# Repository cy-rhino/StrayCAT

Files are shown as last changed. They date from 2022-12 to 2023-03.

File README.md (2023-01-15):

# StrayCAT
EtherCAT slave board using LAN9252

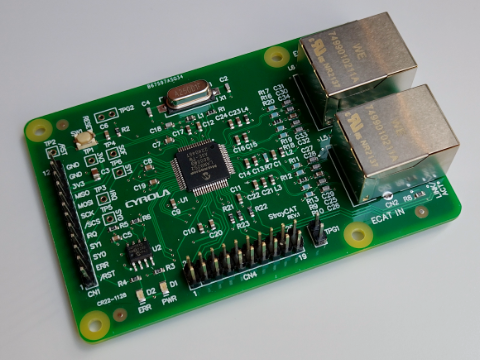
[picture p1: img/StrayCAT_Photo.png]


The design CAD is CircuitStudio. Board dimensions and hole locations are Raspberry Pi compliant, but other component placement is original and not mechanically compatible with any product. The SPI communication port conforms to the EasyCAT PRO pinout.

This stray board has not been tested by EtherCAT conformance testing and does not have the EtherCAT logo printed on it.

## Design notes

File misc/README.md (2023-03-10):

### Misc. Codes
This directory stores miscellaneous source code.

- StrayCAT_Master  
C# implementation software master for Windows  

- StrayCAT_Slave  
Test sketch using Arduino based slave device

##### Special Thanks
This repository builds on ideas and techniques devised by pioneers. I would like to pay special tribute to the following people and organizations.

- Bizan Nishimura, [SOEM.NET](https://github.com/lipoyang/SOEM.NET) conceptor
- Hernando Barragán, Arduino originator
- AB&T, EasyCAT and the Library developer
- RT-Labs, Open EtherCAT Society

##### Trademark
EtherCAT is registered trademark and patented technology, licensed by Beckhoff Automation GmbH, Germany.

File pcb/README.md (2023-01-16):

### PCB Layout

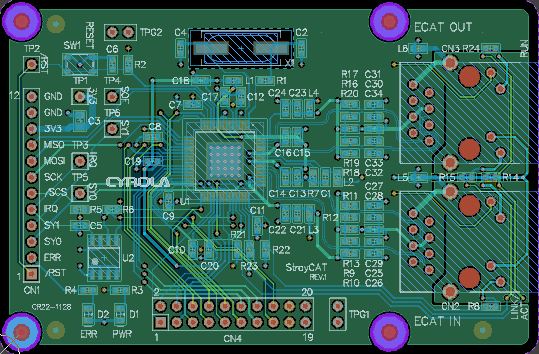
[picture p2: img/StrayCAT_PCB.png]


### PCB Order Information

| Item | Value |
|:---|:---|
| Size | 85mm * 56mm |
| Layers | 4Layers |
| Thickness | 1.6mm |
| Min Track/Spacing | 5/5mil |
| Min Hole Size | 0.3mm |
| Finished Copper | 1oz. Cu |

The order of the layers are as follows.

| Layer | Filename | Usage  |
|:---|:---|:---|
| L1 | StrayCAT.GTL | Top |
| L2 | StrayCAT.G1  | GND |
| L3 | StrayCAT.G2  | 3.3V |
| L4 | StrayCAT.GBL | Bottom |

- GTP layer allows simultaneous production of paste mask.
- GKO layer assigns the board outline.
- TXT file assigns the NC drill data.

### Layer Stack-up 

This Gerber data is impedance-matched based on the assumption that the order will be placed with a factory that manufactures the following board specifications.

| Item | Value |
|:---|:---|
|Trace Thickness | 0.035mm(1.378mil)  |
|Dielectric Thickness | 0.175mm(6.89mil) |
|Dielectric Constant  | 4.29 |

The trace width of the MDI transmission line is 6.929mil and the trace spacing is adjusted to 5.41mil so that the differential impedance is 100 ohms.

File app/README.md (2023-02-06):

# StrayCAT ESI Tool
 ESI .xml file generator

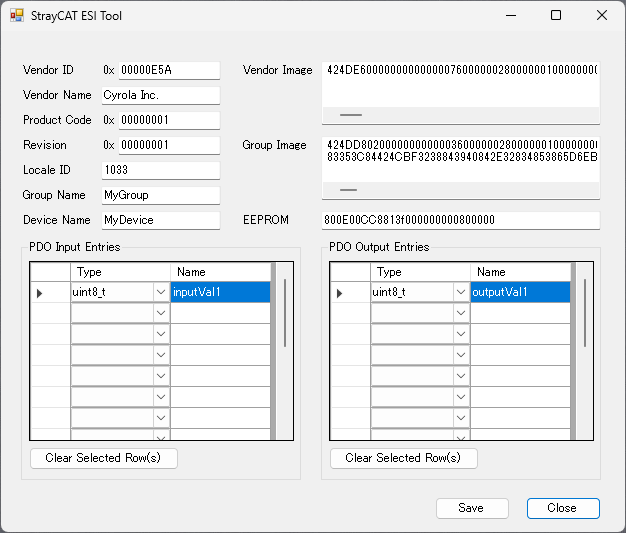
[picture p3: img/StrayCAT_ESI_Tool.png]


This tool is developed in VB.NET. It has only one form and the source code is written in a concise manner. The parameters that cannot be set in the form are hard-coded, so they can be easily modified using Visual Studio.

Originally, a function to write out binary file is also needed, but I do not plan to implement it because I do not have the necessary knowledge. A write tool is required to write the ESI to the EEPROM on the StrayCAT board. This tool is included in the archive of the ET9300 EtherCAT SSC Tool provided by Beckhoff.

To simplify checking the operation, a header file is output for use with the EasyCAT library.

This tool has not yet been fully tested. Users must check the generated xml and correct any problems they find.

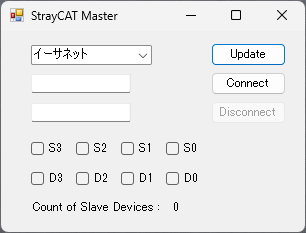
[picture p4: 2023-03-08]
img/StrayCAT_Master.png

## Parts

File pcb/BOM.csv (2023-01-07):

Designator | Qty. | Manufacturer Part Number | Description | Manufacturer
C1, C5, C6, C7, C8, C9, C10, C11, C12, C14, C16, C19, C20, C22, C24 | 15 | CGA3E2X7R1H104K080AA | 1608 0.1uF 50V X7R 10% | TDK
C2, C4 | 2 | CGA3E2C0G1H180J080AA | 1608 18pF 50V C0G 5% | TDK
C3 | 1 | CGA4J1X5R1C106K125AC | 2012 10uF 16V X5R 10% | TDK
C13, C15, C17, C21, C23 | 5 | CGA3E1X7R1E105K080AC | 1608 1uF 25V X7R 10% | TDK
C18 | 1 | CGA3E2C0G1H471J080AA | 1608 470pF 50V C0G 5% | TDK
C25, C26, C27, C28, C30, C31, C32, C33 | 8 | CGA3E2C0G1H100D080AA | 1608 10pF 50V C0G 5% | TDK
C29, C34 | 2 | CGA3E2X7R1H223K080AA | 1608 0.022uF 50V X7R 10% | TDK
CN2, CN3 | 2 | 7499010211A | WE-RJ45LAN | Würth Elektronik
D1 | 1 | APT2012QGW | 2012 Chip LED Green | Kingbright
D2 | 1 | APT2012NW | 2012 Chip LED Orange | Kingbright
L1, L2, L3, L4 | 4 | BLM18EG221SN1D | Chip Ferrite Bead | Murata
L5, L6 | 2 | BLM18PG330SN1D | Chip Ferrite Bead | Murata
R1, R13, R20 | 3 | RK73Z1JTTD | 1608 0-Ohm 1A | KOA
R2, R21, R22, R23 | 4 | RK73B1JTTD103J | 1608 10kOhm 5% 1/10W | KOA
R3, R4, R8, R14, R15, R24 | 6 | RK73B1JTTD102J | 1608 1kOhm 5% 1/8W | KOA
R5, R6 | 2 | RK73B1JTTD472J | 1608 4.7kOhm 5% 1/10W | KOA
R7 | 1 | RK73H1JTTD1212F | 1608 12.1kOhm 1% 1/10W | KOA
R9, R10, R11, R12, R16, R17, R18, R19 | 8 | RK73H1JTTD49R9F | 1608 49.9Ohm 1% 1/8W | KOA
SW1 | 1 | SKRPABE010 | SPST Switch N/O 1.57N | ALPS
U1 | 1 | LAN9252I/PT | EtherCAT Slave Controller | Microchip
U2 | 1 | 24FC512-I/SN | 512kBit I2C Serial EEPROM | Microchip
X1 | 1 | ABLS-25.000MHZ-B2F-T | HC/49US 25MHz Crystal | Abracon

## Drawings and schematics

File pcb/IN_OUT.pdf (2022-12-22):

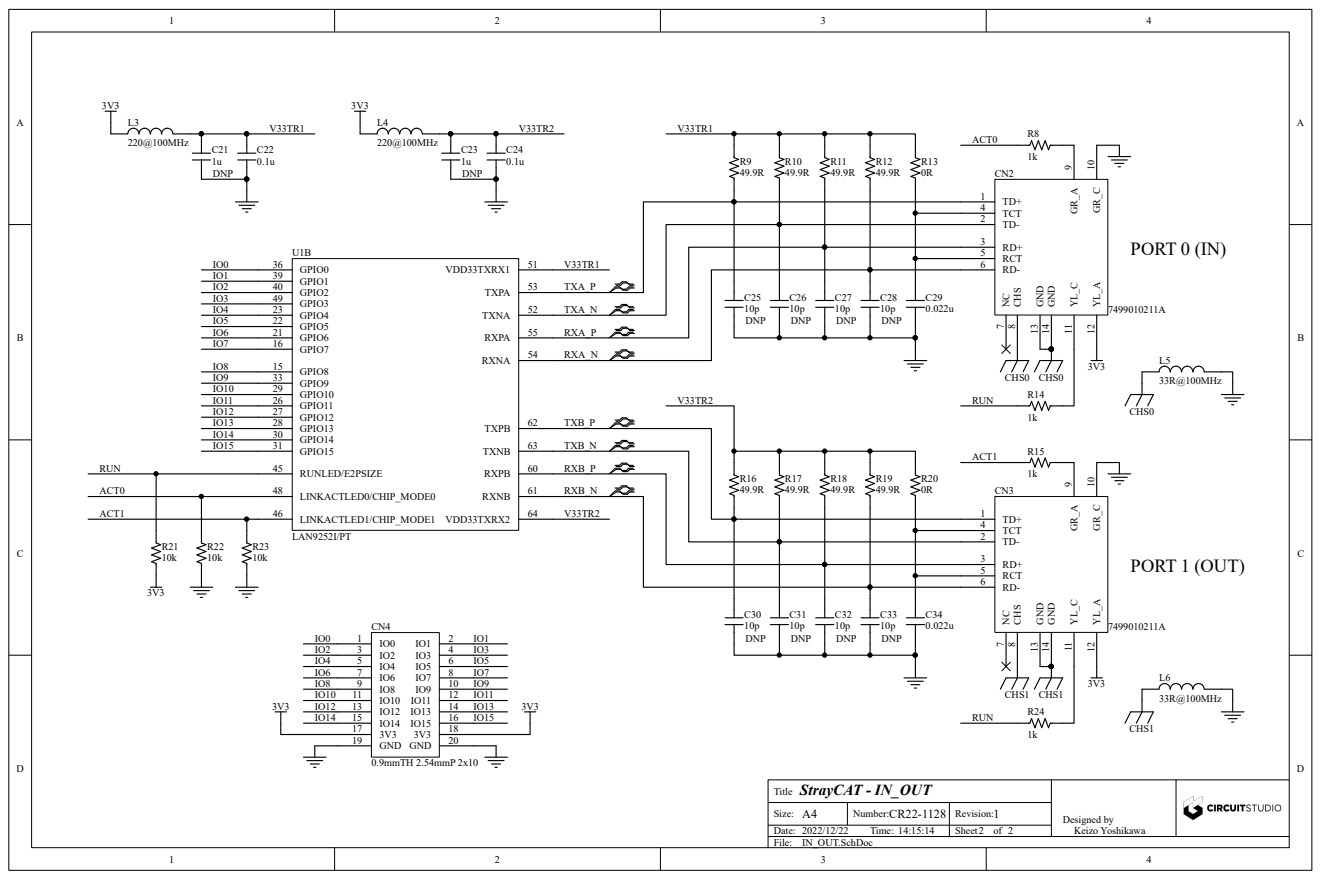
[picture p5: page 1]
Str; RUN; RXN; RUN ACT0 ACT1; RUN RUN; CHS 8; GND 13; GND 14

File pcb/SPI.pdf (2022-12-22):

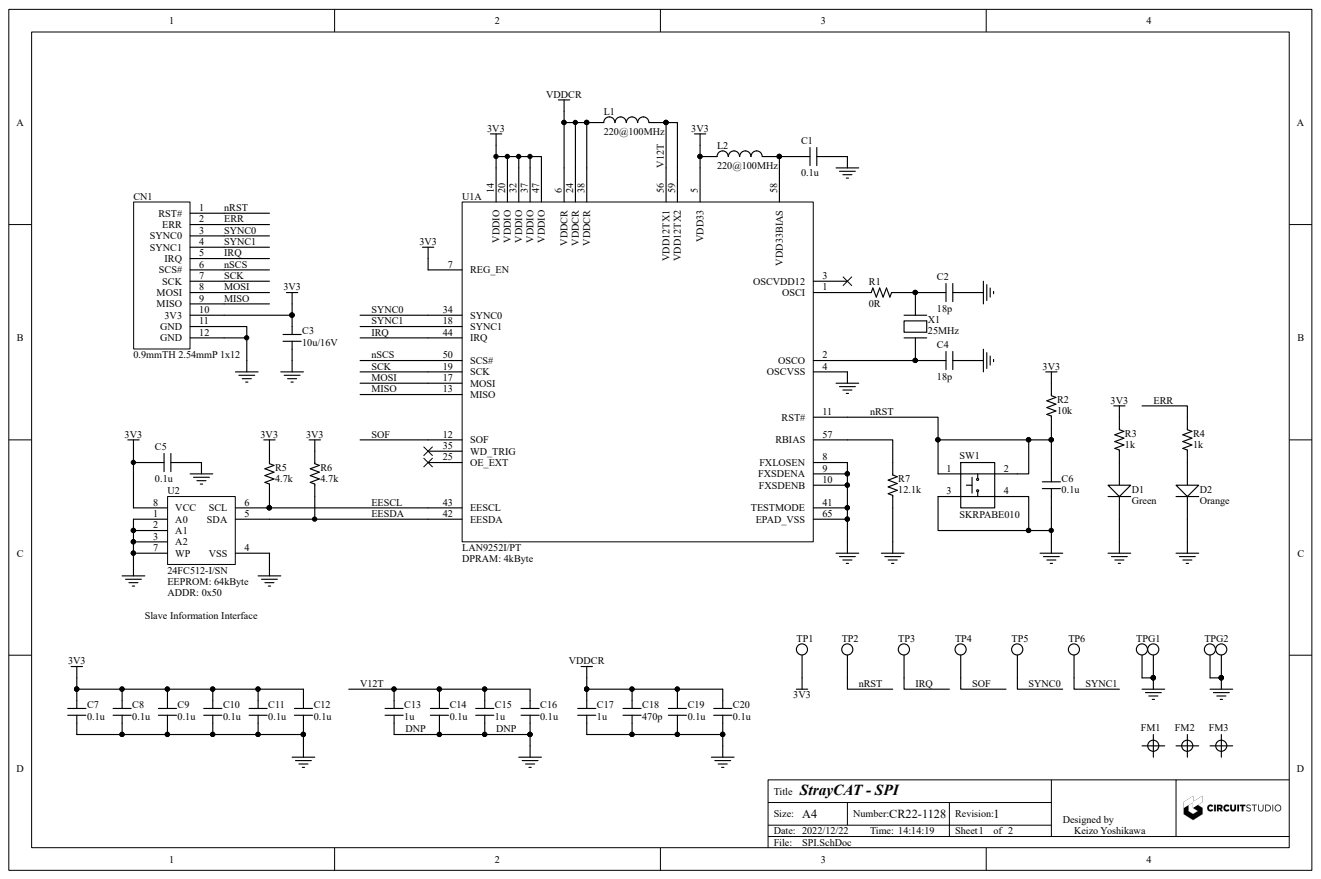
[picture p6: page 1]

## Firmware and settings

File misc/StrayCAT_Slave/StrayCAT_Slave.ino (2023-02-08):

/*
 *  StrayCAT Slave with an Arduino
 *
 *  signal voltage : 3.3V
 *  user interface : 2 Trimpots, 4 LEDs, 4 Switches
 */

#define CUSTOM                // custom mode

#include "StrayCAT_Custom.h"  // created by StrayCAT ESI Tool
#include "EasyCAT.h"          // AB&T EasyCAT Library V2.0 is required
#include <SPI.h>

EasyCAT EASYCAT;              // EasyCAT instantiation

const int Ana0 = A0;          // analog input 0
const int Ana1 = A1;          // analog input 1

const int BitOut0 = A2;       // digital output bit 0
const int BitOut1 = A3;       // digital output bit 1
const int BitOut2 = A4;       // digital output bit 2
const int BitOut3 = A5;       // digital output bit 3

const int BitIn0 = 3;         // digital input  bit 0
const int BitIn1 = 5;         // digital input  bit 1
const int BitIn2 = 6;         // digital input  bit 2
const int BitIn3 = 7;         // digital input  bit 3

uint16_t CountUp;             // rising ramp
uint8_t  CountDown;           // falling ramp

unsigned long Millis = 0;
unsigned long PreviousMillis = 0;
unsigned long PreviousRamp = 0;
unsigned long PreviousCycle = 0;

void setup()
{
  pinMode(BitOut0, OUTPUT);
  pinMode(BitOut1, OUTPUT);
  pinMode(BitOut2, OUTPUT);
  pinMode(BitOut3, OUTPUT);
  pinMode(BitIn0, INPUT_PULLUP);
  pinMode(BitIn1, INPUT_PULLUP);
  pinMode(BitIn2, INPUT_PULLUP);
  pinMode(BitIn3, INPUT_PULLUP);

  CountUp = 0x0000;
  CountDown = 0x00;

  if (EASYCAT.Init() == true)
  {
    Serial.print("initialized");
  } else {
    Serial.print("initialization failed");
    pinMode(13, OUTPUT);
    while(1)
    {
      digitalWrite(13, LOW);
      delay(500);
      digitalWrite(13, HIGH);
      delay(500);
    }
  }
  PreviousMillis = millis();
}

void loop()
{
  EASYCAT.MainTask();   // the task cycle and the Master cycle are asynchronous
  Application();        // user applications
}

void Application()
{
  uint16_t Analog0;
  uint16_t Analog1;

  Millis = millis();
  if (Millis - PreviousMillis >= 10)                    // cycle time : 10mSec
  {
    PreviousMillis = Millis;

    Analog0 = analogRead(Ana0);                         // read 10 bit analog input 0
    Analog0 = Analog0 << 6;                             // normalize it on 16 bits
    EASYCAT.BufferIn.Cust.Analog_0 = Analog0;           // and put the result into input Byte 0

    Analog1 = analogRead(Ana1);                         // read 10 bit analog input 1
    Analog1 = Analog1 << 6;                             // normalize it on 16 bits
    EASYCAT.BufferIn.Cust.Analog_1 = Analog1;           // and put the result into input Byte 2

    if (EASYCAT.BufferOut.Cust.Leds & (1<<0)) {         // the 4 output bits are mapped to the
      digitalWrite(BitOut0, HIGH);                      // lower nibble of output Byte 0
    } else {
      digitalWrite(BitOut0, LOW);
    }
    if (EASYCAT.BufferOut.Cust.Leds & (1<<1)) {
      digitalWrite(BitOut1, HIGH);
    } else {
      digitalWrite(BitOut1, LOW);
    }
    if (EASYCAT.BufferOut.Cust.Leds & (1<<2)) {
      digitalWrite(BitOut2, HIGH);
    } else {
      digitalWrite(BitOut2, LOW);
    }
    if (EASYCAT.BufferOut.Cust.Leds & (1<<3)) {
      digitalWrite(BitOut3, HIGH);
    } else {
      digitalWrite(BitOut3, LOW);
    }

    if (digitalRead(BitIn0)) {                          // the 4 input pins are mapped to the
      EASYCAT.BufferIn.Cust.DipSwitches |=  (1<<0);     // lower nibble of input Byte 6
    } else {                                            // we read each pin and write it
      EASYCAT.BufferIn.Cust.DipSwitches &= ~(1<<0);     // to the corresponding bit
    }
    if (digitalRead(BitIn1)) {
      EASYCAT.BufferIn.Cust.DipSwitches |=  (1<<1);
    } else {
      EASYCAT.BufferIn.Cust.DipSwitches &= ~(1<<1);
    }
    if (digitalRead(BitIn2)) {
      EASYCAT.BufferIn.Cust.DipSwitches |=  (1<<2);
    } else {
      EASYCAT.BufferIn.Cust.DipSwitches &= ~(1<<2);
    }
    if (digitalRead(BitIn3)) {
      EASYCAT.BufferIn.Cust.DipSwitches |=  (1<<3);
    } else {
      EASYCAT.BufferIn.Cust.DipSwitches &= ~(1<<3);
    }

    Millis = millis();                                  // each 100mSec
    if (Millis - PreviousRamp >= 100)
    {
      PreviousRamp = Millis;
      CountUp += 256;                                   // we increment the variable CountUp
      CountDown--;                                      // and decrement CountDown
    }

    EASYCAT.BufferIn.Cust.Bit16_RisingRamp = CountUp;   // medium speed rising ramp
    EASYCAT.BufferIn.Cust.Bit8_FallingRamp = CountDown; // medium speed falling ramp
  }
}
